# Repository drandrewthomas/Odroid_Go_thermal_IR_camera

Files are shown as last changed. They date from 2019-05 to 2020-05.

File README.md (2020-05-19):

# Odroid Go thermal infrared camera

## Update 28th April 2020: The firmware has been updated to v1.1, with lots of new features and improvements!

## Introduction

This is a simple, yet very useful, IR (infrared) thermal camera project for the Odroid Go handheld ESP32 system. It allows saving of data to an SD card as well as having a Bluetooth interface to wirelessly get data off the camera to a computer, tablet or mobile phone. It's based on the MLX90640 32x24 pixel infrared thermal array modules that you can get relatively inexpensively many places online. Here's a short list of some of it's features:

* Onscreen display of the IR image, with a movable cursor to let you query the temperature for any single pixel (press up, down, left and right on the + control to move the cursor).
* A range of colour maps, which are easily added to in the Arduino code.
* A zoom button so you can switch the IR image to/from full-screen mode.
* Saving of data to the SD card on your ODroid GO in text CSV format for later analysis.
* A fever screening colour map, which shows temperatures above 36C in red to indicate when checking for a fever may be necessary (not for medical diagnosis).
* In fever checking mode IR images with temperatures above 36C are indicated by an audible beep, to help with rapid screening of your family and friends.
* An on-screen battery indicator, so you know when to recharge your GO.
* A Bluetooth interface that lets you take full control of the IR camera, including transferring the IR data to a PC as ASCII text or binary data.
* 3D printing STL files to make a forward-facing or rear-facing case to protect your thermal IR module.

Below is a photo of the project in action on an Odroid GO:

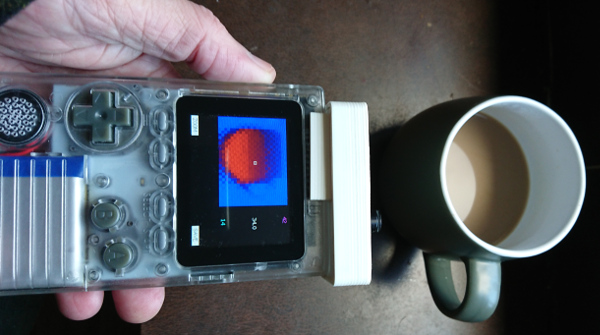
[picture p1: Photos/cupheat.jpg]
The thermal camera in action


## Using the Arduino code

There are two ways to use the thermal camera code. The really simple way is to go to the 'FW file' folder and copy the 'goircam.fw' file to the firmware folder on your Odroid Go SD card. Then when you turn the Go on with the B button held down you should get an option to load the camera firmware. Obviously you'll need the camera built and attached for the firmware to run.

The more advanced way is for people who want to use the Arduino IDE to edit or build the firmware. To do that just use the files in the 'Arduino code' folder as you would do for code in any other Arduino project you have. All of the details are available on the Odroid Go website for setting up the Arduino IDE for the Go, so I won't cover it here.

If you're using the Arduino IDE method and want to create a firmware file, as described on the Go site, the graphics for use with the MKFW utility are included in the 'Graphics' folder.

## Building the thermal camera module

Building the module is very simple, as it uses just the MLX90640 module, with wires for ground, VCC, SCL and SDA (so just power and I2C). According to the Go wiki the header pinout is as follows, so you can wire the module easily even just using some wires and a breadboard.

| Header Pin | Function |
| --- |:---:|
| 1 | GND |
| 4 | SDA |
| 5 | SCL |
| 6 | VCC |

Once you've got things wired up and tested, the simplicity of the circuit makes it very simple to solder up some header pins on a piece of veroboard to make a more robust connector for the Odroid Go header sockets. Below is a photo of how I did that. I put the header pins on top of the veroboard and soldered the wires to the track on the back, which meant the wires didn't obstruct the connection, although you could just use a bigger piece of veroboard too.

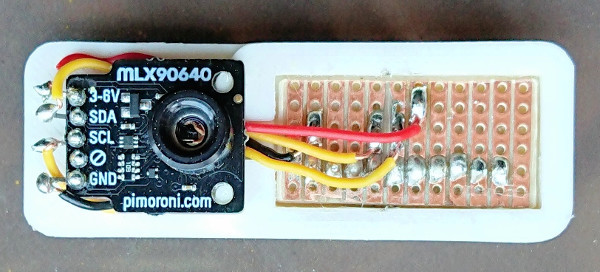
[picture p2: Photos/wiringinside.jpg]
A photo of the circuit


## Making a 3D printed enclosure

The 'Case 3D model' folder includes files I used to make 3D printed enclosures. The STL files are designed for the Pimoroni MLX90640 module I used. If that doesn't work for your needs, or the MLX90640 module you have, the OpenSCAD files are included so you can make a custom version. By cutting the veroboard to the right size the IR module should fit perfectly into the back of the enclosure, leaving the header pins properly positioned as shown in the front-facing example photo below. The veroboard was glued in, and it's necessary to check the pins as the glue goes off to make sure they stay perpendicular to the enclosure.

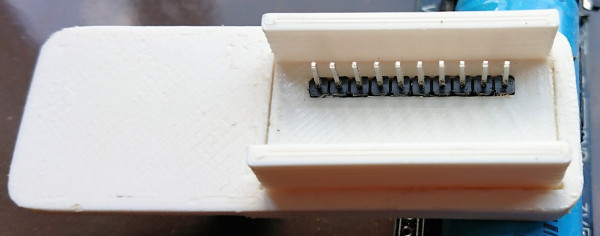
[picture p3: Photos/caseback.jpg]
A photo of the back of the enclosure showing the header pins glued in


## Useful links

Below are some links that may be useful if you decide to build this project.

The Odroid Go Wiki is a useful resource for all Go things: [https://wiki.odroid.com/odroid_go/odroid_go](https://wiki.odroid.com/odroid_go/odroid_go)

The Wiki page for a 16x2 I2C LCD project contains details of how to connect an I2C module to the Go header: [https://wiki.odroid.com/odroid_go/arduino/09_16x2lcd_i2c](https://wiki.odroid.com/odroid_go/arduino/09_16x2lcd_i2c)

The front facing 3D printed case can also be downloaded from Thingiverse: [https://www.thingiverse.com/thing:3648653](https://www.thingiverse.com/thing:3648653)

And the rear facing 3D printed case can also be downloaded from MyMiniFactory: [https://www.myminifactory.com/object/3d-print-odroid-go-thermal-infrared-ir-camera-ideal-for-covid-coronavirus-screening-122446](https://www.myminifactory.com/object/3d-print-odroid-go-thermal-infrared-ir-camera-ideal-for-covid-coronavirus-screening-122446)

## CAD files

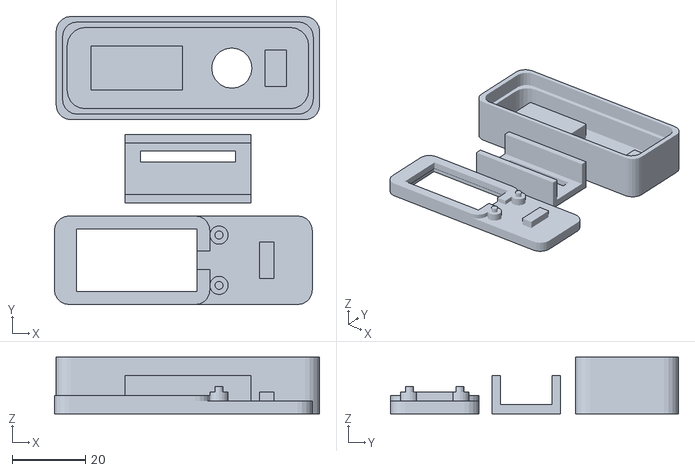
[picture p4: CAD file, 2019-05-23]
Case 3D model/Front facing version/goircam_v1.stl
72.5 x 78.7 x 15.5

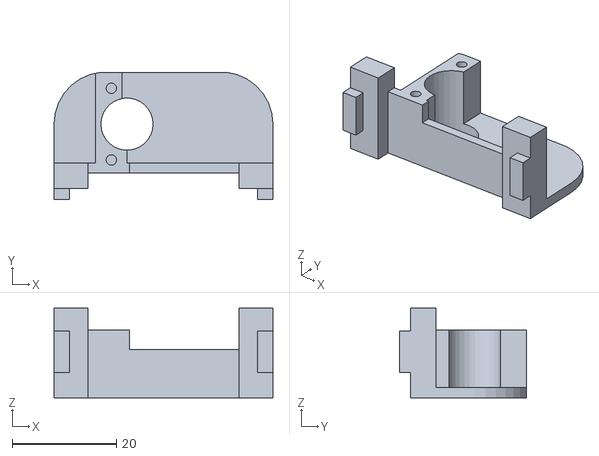
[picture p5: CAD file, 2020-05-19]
Case 3D model/Rear facing version/holddown.stl
42.0 x 24.4 x 17.2

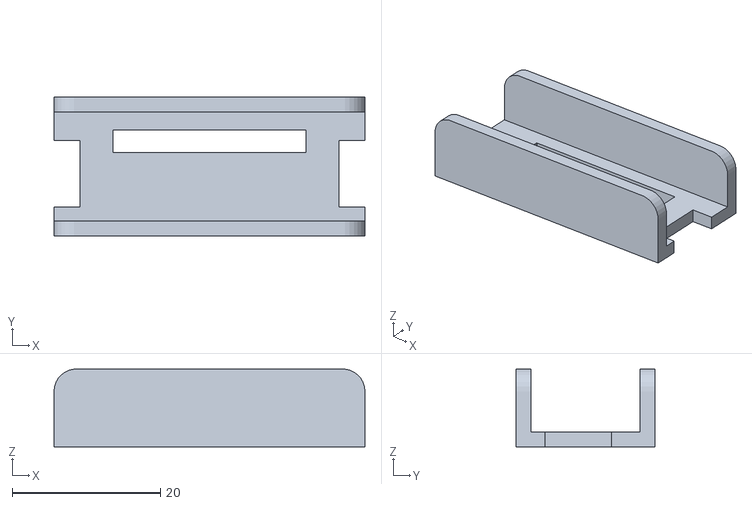
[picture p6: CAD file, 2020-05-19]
Case 3D model/Rear facing version/headeradapter.stl
42.0 x 18.8 x 10.5

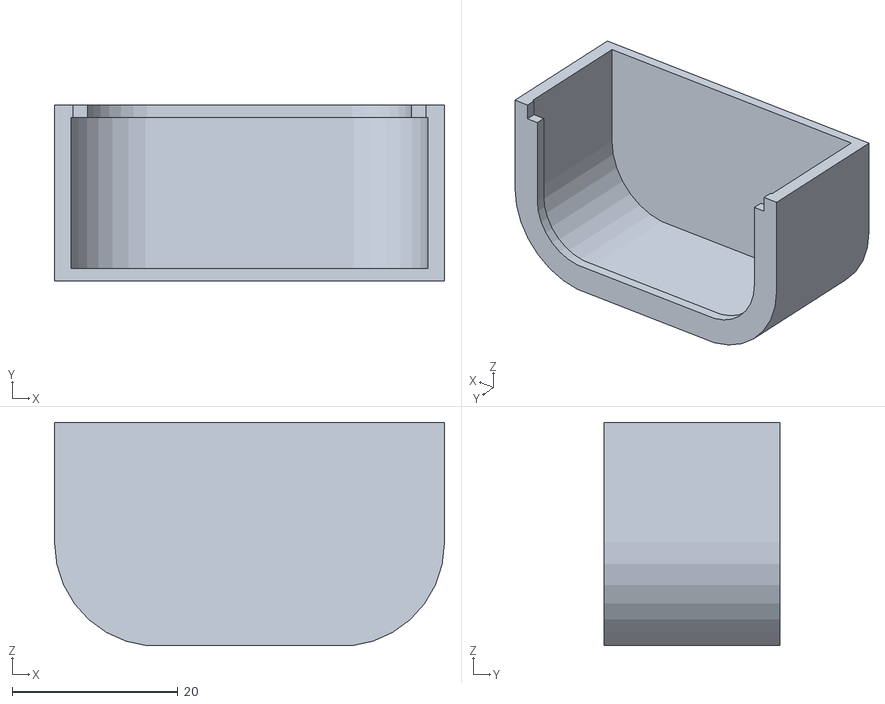
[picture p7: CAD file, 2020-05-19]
Case 3D model/Rear facing version/cover.stl
47.0 x 21.2 x 26.9

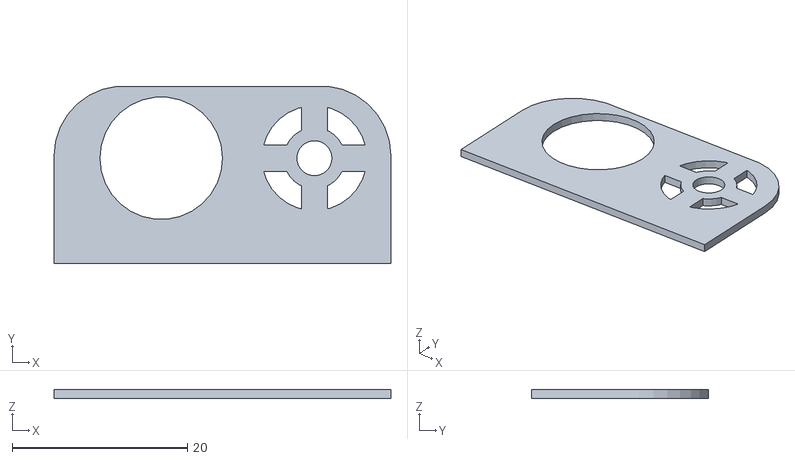
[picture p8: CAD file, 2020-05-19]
Case 3D model/Rear facing version/fascia.stl
38.5 x 20.3 x 1.00

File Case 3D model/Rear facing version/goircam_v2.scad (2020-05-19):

$fn=30;
trad=10;
brad=3;

//rotate([0,180,0]) makeheaderadapter();
//rotate([-90,0,0]) makeholddown();
//rotate([-90,0,0]) makefascia();
rotate([0,180,0]) makecover();

module makecover()
{
  color("#0000ff")
  {
    difference()
    {
      translate([0,0,0]) roundedbox(42+5,33+5,18.75+2.5,10+2.5,3);
      translate([0,0,0]) roundedbox(42+1,33+1,18.75+2.5-3,10,3);
      translate([0,10,0]) roundedbox(42-5+2,33-5+2,5,8,3);
      translate([0,0,-33+10.5-2]) cube([100,100,33],center=true);
      intersection()
      {
        translate([0,10,2.25]) roundedbox(42.5,33,18.75,10,3);
        translate([0,10,-16+2.25]) cube([100,100,16],center=true);
      }
    }
  }
}

module makeheaderadapter()
{
  difference()
  {
    roundedbox(42,33,18.75,10,3);
    translate([0,0,-16]) cube([45,14.7,16],center=true);
    translate([0,3.4,-16.5+8]) cube([26,3,6],center=true);
    translate([0,0,33-25+2.5]) cube([45,45,25+8],center=true);
    translate([21-1.5,-1,-6]) cube([3+1,8+1,40],center=true);
    translate([-21+1.5,-1,-6]) cube([3+1,8+1,40],center=true);
  }
}

module makeholddown()
{
  color("#ff0000")
  {
    union()
    {
      difference()
      {
        roundedbox(42,33,18.75,10,3);
        translate([0,0,-33+10.5+0.2]) cube([100,100,33],center=true);
        translate([0,18.75/2,0]) cube([100,3,100],center=true);
        translate([21,-3.5,12.5+3]) cube([56,18.75,33],center=true);
        translate([21-1,-3.5,12.5+3+10]) cube([56,18.75,33],center=true);
        translate([-21,-3.5,12.5+3]) cube([16,18.75,33],center=true);
        translate([0,-5-9.5,12.5+3]) cube([50,18.75,33],center=true);
        translate([0,0,-4.35]) cube([29,50,3],center=true);
        translate([4,-18.75/2,-2]) cube([21,16,3],center=true);
        translate([-4,-18.75/2,-2]) cube([21,8.5,3],center=true);
        translate([-7,8,6.5]) rotate([90,0,0]) cylinder(h=50,r=5,center=true);
        translate([-10,-5,6.5+(13.75/2)]) rotate([90,0,0]) cylinder(h=15,r=1,center=true);
        translate([-10,-5,6.5-(13.75/2)]) rotate([90,0,0]) cylinder(h=15,r=1,center=true);
      }
      translate([21-1.5,-1,-6]) cube([3,8,4],center=true);
      translate([-21+1.5,-1,-6]) cube([3,8,4],center=true);
    }
  }
}

module makefascia()
{
  color("#00ff00")
  {
    difference()
    {
      roundedbox(42-5+2-0.5,33-5+2-0.5,1,8,3);
      translate([0,0,-33+10.5+0.2+0.25]) cube([100,100,33],center=true);
      translate([-7,8,6.5]) rotate([90,0,0]) cylinder(h=50,r=7,center=true);
      difference()
      {
        translate([10.5,8,6.5]) rotate([90,0,0]) cylinder(h=50,r=6,center=true);
        translate([10.5,8,6.5]) cube([3,100,100],center=true);
        translate([10.5,8,6.5]) cube([100,100,3],center=true);
        translate([10.5,8,6.5]) rotate([90,0,0]) cylinder(h=50,r=3.5,center=true);
      }
      translate([10.5,8,6.5]) rotate([90,0,0]) cylinder(h=50,r=2,center=true);
    }
  }
}

module roundedbox(w,h,d,trad,brad)
{
  hull()
  {
    translate([-(w/2)+brad,0,-(h/2)+brad]) rotate([90,0,0]) cylinder(h=d,r=brad,center=true);
    translate([(w/2)-brad,0,-(h/2)+brad]) rotate([90,0,0]) cylinder(h=d,r=brad, center=true);
    translate([(w/2)-trad,0,(h/2)-trad]) rotate([90,0,0]) cylinder(h=d,r=trad,center=true);
    translate([-(w/2)+trad,0,(h/2)-trad]) rotate([90,0,0]) cylinder(h=d,r=trad,center=true);
  }
}

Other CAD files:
Case 3D model/Front facing version/goircam_v1.scad

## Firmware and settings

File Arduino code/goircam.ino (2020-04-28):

#include <odroid_go.h>
#include <driver/adc.h>
#include "sensors/Wire.h"
#include "MLX90640_I2C_Driver.h"
#include "MLX90640_API.h"
#include "BluetoothSerial.h"
#include "FS.h"
#include "SD.h"
#include "SPI.h"

#define RESISTANCE_NUM 2
#define DEFAULT_VREF 1100
static esp_adc_cal_characteristics_t adc_chars;

#define TA_SHIFT 8 //Default shift for MLX90640 in open air
const byte MLX90640_address = 0x33;
static float mlx90640To[768];
paramsMLX90640 mlx90640;

BluetoothSerial serialBT;

bool dooverlay=true,saved=false,havesd=false;
int boxx=16,boxy=12,cmap=0,cr,cg,cb;
long gottime,firstsave=-1,battime;
float ambient,battery,fever=36,mn,mx;

void setup()
{
  Serial.begin(115200); // MUST BE BEFORE GO.BEGIN()!!!!!
  serialBT.begin("GO IR Camera");
  GO.begin();
  Wire.begin(15,4);
  Wire.setClock(400000);
  Serial.println("Starting...");
  Serial.println();
  adc1_config_width(ADC_WIDTH_BIT_12);
  adc1_config_channel_atten(ADC1_CHANNEL_0, ADC_ATTEN_DB_11);
  esp_adc_cal_characterize(ADC_UNIT_1, ADC_ATTEN_DB_11, ADC_WIDTH_BIT_12, DEFAULT_VREF, &adc_chars);
  int status;
  uint16_t eeMLX90640[832];
  status = MLX90640_DumpEE(MLX90640_address, eeMLX90640);
  if (status != 0)
    Serial.println("Failed to load system parameters");
  status = MLX90640_ExtractParameters(eeMLX90640, &mlx90640);
  if (status != 0)
    Serial.println("Parameter extraction failed");
  MLX90640_SetRefreshRate(MLX90640_address,0x03);
  if(SD.begin()) havesd=true;
  else Serial.println("Card Mount Failed");
  GO.lcd.setTextFont(4);
  GO.lcd.setTextColor(WHITE);
  GO.lcd.setTextDatum(MC_DATUM);
//  GO.lcd.setCursor(160,120);
  GO.lcd.drawString("IR Camera v1.1",160,80);
  GO.lcd.setTextFont(2);
  GO.lcd.drawString("by Andrew Thomas",160,150);
  GO.lcd.drawString("2019-2020",160,170);
  GO.lcd.setTextFont(4);
  delay(1000);
  Serial.println("Getting initial IR frame...");
  getirframe();
  calcminmax();
  drawtodisplay(true);
  Serial.println("Setup done");
}

void loop()
{
  char inbyte;
  if(serialBT.available()>0)
  {
    inbyte=serialBT.read();
    switch(inbyte)
    {
      case '0': cmap=0; break;
      case '1': cmap=1; break;
      case '2': cmap=2; break;
      case 'a': sendtoserialtext();
                break;
      case 'b': sendtoserialbinary();
                break;
      case 'd': getirframe();
                calcminmax();
                break;
      case 'n': makebeep(2000,500);
                break;
      case 'o': dooverlay=true;
                break;
      case 's': savetosdcard();
                saved=true;
                break;
      case 'u': drawtodisplay(true);
                break;
      case 'v': serialBT.println("IR Camera v1.1");
                break;
      case 'z': dooverlay=false;
                break;
    }
  }
  GO.update();
  if(GO.BtnA.isPressed()==1)
  {
    getirframe();
    calcminmax();
    drawtodisplay(true);
    if(mx>=fever && cmap==2) makebeep(3000,1000);
  }
  if(GO.BtnMenu.isPressed()==1)
  {
    while(GO.BtnMenu.isPressed()==1){GO.update();delay(50);}
    if(dooverlay==true) dooverlay=false;
    else dooverlay=true;
    GO.lcd.clearDisplay();
    drawtodisplay(true);
  }
  if(GO.BtnVolume.isPressed()==1)
  {
    while(GO.BtnVolume.isPressed()==1){GO.update();delay(50);}
    cmap++;
    if(cmap>2) cmap=0;
    drawtodisplay(false);
  }
  if(GO.BtnSelect.isPressed()==1)
  {
    while(GO.BtnSelect.isPressed()==1){GO.update();delay(50);}
  }
  if(GO.BtnStart.isPressed()==1)
  {
    if(saved==false)
    {
      savetosdcard();
      saved=true;
      drawtodisplay(true);
    }
  }
  if(GO.JOY_Y.isAxisPressed()==1)
  {
    if(boxy<23 && dooverlay==true)
    {
      boxy++;
      drawtodisplay(false);
      delay(50);
    }
  }
  if(GO.JOY_Y.isAxisPressed()==2)
  {
    if(boxy>0 && dooverlay==true)
    {
      while(GO.JOY_Y.isAxisPressed()!=0){GO.update();delay(50);}
      boxy--;
      drawtodisplay(false);
      delay(50);
    }
  }
  if(GO.JOY_X.isAxisPressed()==1)
  {
    if(boxx<31 && dooverlay==true)
    {
      while(GO.JOY_X.isAxisPressed()!=0){GO.update();delay(50);}
      boxx++;
      drawtodisplay(false);
      delay(50);
    }
  }
  if(GO.JOY_X.isAxisPressed()==2)
  {
    if(boxx>0 && dooverlay==true)
    {
      while(GO.JOY_X.isAxisPressed()!=0){GO.update();delay(50);}
      boxx--;
      drawtodisplay(false);
      delay(50);
    }
  }
  if((millis()-battime)>30000) updatebattery();
}

void updatebattery()
{
  readbattery();
  drawbattery();
}

void calcminmax()
{
  int c;
  mn=99999,mx=-99999;
  for(c=0;c<768;c++)
  {
    if(mlx90640To[c]>mx) mx=mlx90640To[c];
    if(mlx90640To[c]<mn) mn=mlx90640To[c];
  }
  mn=int(mn);
  mx=int(mx+1);
  if(mn<-30) mn=-30;
  if(mx>300) mx=300;  
}

void drawtodisplay(bool cls)
{
  float mid,val;
  uint16_t x,y,ind,r,g,b,col;
  uint16_t xw=10,yw=10,xoff=0,yoff=0;
  if(dooverlay==true)
  {
    xw=7;
    yw=7;
    xoff=0;
    yoff=0;
  }
  mid=mlx90640To[((23-boxy)*32)+boxx];
  if(cls==true) GO.lcd.clearDisplay();
  for(y=0;y<24;y++)
  {
    for(x=0;x<32;x++)
    {
      ind=(y*32)+x;
      val=mlx90640To[ind];
      docolourmapping(val,mn,mx);
      col=GO.lcd.color565(cr,cg,cb);
      GO.lcd.fillRect(xoff+(x*xw),yoff+((24*yw)-(y*yw)),xw,yw,col);
    }
  }
  if(dooverlay==true)
  {
    if(cls==false) GO.lcd.fillRect(xoff+(32*xw)+5,0,320-(xoff+(32*xw)),210,BLACK);
    GO.lcd.setTextFont(2);
    GO.lcd.setTextSize(1);
    GO.lcd.setTextDatum(ML_DATUM);
    GO.lcd.setTextColor(MAGENTA,BLACK);
    GO.lcd.drawNumber(int(mx),255,yoff+15);
    GO.lcd.setTextColor(CYAN,BLACK);
    GO.lcd.drawNumber(int(mn),255,yoff+(24*yw)-2);
    GO.lcd.setTextColor(WHITE,BLACK);
    GO.lcd.drawFloat(mid,1,255,yoff+((24*yw)/2)+yw);
    GO.lcd.drawRect(xoff+(boxx*xw),yoff+(boxy*yw),xw,yw,WHITE);
    // Draw button labels
    GO.lcd.setTextFont(2);
    GO.lcd.setTextSize(1);
    GO.lcd.setTextColor(BLACK,WHITE);
    GO.lcd.setTextDatum(ML_DATUM);
    GO.lcd.drawString(" ZOOM ",0,230);
    switch(cmap)
    {
      case 0: GO.lcd.drawString(" B R ",82,230);
      break;
      case 1: GO.lcd.drawString(" Y R ",82,230);
      break;
      case 2: GO.lcd.drawString(" FEV ",82,230);
      break;
    }
    if(saved==false && havesd==true)
    {
      GO.lcd.setTextDatum(MR_DATUM);
      GO.lcd.drawString(" SAVE  ",320,230);
    }
    GO.lcd.setTextFont(2);
    GO.lcd.setTextSize(1);
    GO.lcd.setTextColor(WHITE,BLACK);
    GO.lcd.drawString("Ambient: "+String(ambient,1)+" C",2,195);
  }
  drawbattery();
}

void drawbattery()
{
  int c,bat,nb,xoff=320-44,yoff=194;
  uint16_t col;
  if(dooverlay==false) yoff+=30;
  col=GO.lcd.color565(0,0,0);
  GO.lcd.fillRect(xoff-4,yoff-4,44,18,col);
  bat=int(map(constrain(battery,3.2,4),3.2,4,0,100));
  nb=bat/20;
  if(nb<=1)
  {
    nb=1;
    col=GO.lcd.color565(255,0,0);
  }
  else col=GO.lcd.color565(0,255,0);
  for(c=0;c<nb;c++)
    GO.lcd.fillRect(xoff+(c*7),yoff,5,10,col);
  col=GO.lcd.color565(255,255,255);
  GO.lcd.drawLine(xoff-3,yoff-3,xoff+36,yoff-3,col);
  GO.lcd.drawLine(xoff-3,yoff+12,xoff+36,yoff+12,col);
  GO.lcd.drawLine(xoff-3,yoff-3,xoff-3,yoff+12,col);
  GO.lcd.drawLine(xoff+36,yoff-3,xoff+36,yoff+2,col);
  GO.lcd.drawLine(xoff+36,yoff+7,xoff+36,yoff+12,col);
  GO.lcd.drawLine(xoff+39,yoff+2,xoff+39,yoff+7,col);
  GO.lcd.drawLine(xoff+36,yoff+2,xoff+39,yoff+2,col);
  GO.lcd.drawLine(xoff+36,yoff+7,xoff+39,yoff+7,col);
}

void docolourmapping(float t,float mn,float mx)
{
  switch(cmap)
  {
    case 0: // Red/blue mapping
            cr=int(map(t,int(mn),int(mx),0,255));
            cg=0;
            cb=int(map(t,int(mn),int(mx),255,0));
            break;
    case 1: // Yellow mapping
            cr=255;
            cg=int(map(t,int(mn),int(mx),255,0));
            cb=0;
            break;
    case 2: // Fever mapping
            if(t<=fever)
            {
              cr=0;
              cg=0;
              cb=int(map(t,int(mn),fever,255,50));
            }
            else
            {
              cr=int(map(t,fever,int(mx),50,255));
              cg=0;
              cb=0;
            }
            break;
  }
}

void getirframe()
{
  for (byte x = 0 ; x < 2 ; x++) //Read both subpages
  {
    uint16_t mlx90640Frame[834];
    int status = MLX90640_GetFrameData(MLX90640_address, mlx90640Frame);
    if (status < 0)
    {
      Serial.print("GetFrame Error: ");
      Serial.println(status);
    }
    float vdd = MLX90640_GetVdd(mlx90640Frame, &mlx90640);
    float Ta = MLX90640_GetTa(mlx90640Frame, &mlx90640);
    float tr = Ta - TA_SHIFT; //Reflected temperature based on the sensor ambient temperature
    float emissivity = 0.95;
    MLX90640_CalculateTo(mlx90640Frame, &mlx90640, emissivity, tr, mlx90640To);
    ambient=Ta;
  }
  gottime=millis();
  boxx=16,boxy=12;
  saved=false;
  readbattery();
}

void sendtoserialtext()
{
  int x,y,ind;
  float val;
  if(firstsave==-1)
  {
    firstsave=millis();
    serialBT.print("0");
  }
  else serialBT.print(gottime-firstsave,DEC);
  serialBT.print(',');
  for(y=0;y<24;y++)
  {
    for(x=0;x<32;x++)
    {
      ind=(y*32)+x;
      val=mlx90640To[ind];
      serialBT.print(val,2);
      serialBT.print(',');
    }
  }
  serialBT.print(ambient,2);
  serialBT.print(',');
  serialBT.println(battery,2);
}

void sendtoserialbinary()
{
  int x,y,ind,val;
  serialBT.write(254);
  serialBT.write(254);
  for(y=0;y<24;y++)
  {
    for(x=0;x<32;x++)
    {
      ind=(y*32)+x;
      val=int((mlx90640To[ind]+50)*100);
      serialBT.write(highByte(val));
      serialBT.write(lowByte(val));
    }
  }
  val=int((ambient+50)*100);
  serialBT.write(highByte(val));
  serialBT.write(lowByte(val));
  val=int(battery*100);
  serialBT.write(highByte(val));
  serialBT.write(lowByte(val));
  serialBT.write(255);
  serialBT.write(255);
}

boolean isConnected()
{
  Wire.beginTransmission((uint8_t)MLX90640_address);
  if (Wire.endTransmission() != 0)
    return (false); //Sensor did not ACK
  return (true);
}

void savetosdcard()
{
  int x,y,ind;
  float val;
  File file=SD.open("/goircam.csv",FILE_APPEND);
  if(!file)
  {
    Serial.println("Failed to open file for appending");
    makebeep(500,500);
    return;
  }
  file.print(gottime,DEC);
  file.print(',');
  for(y=0;y<24;y++)
  {
    for(x=0;x<32;x++)
    {
      ind=(y*32)+x;
      val=mlx90640To[ind];
      file.print(val,2);
      file.print(',');
    }
  }
  file.println(ambient,DEC);
  file.close();
}

void makebeep(int pitch,int duration)
{
  GO.Speaker.setVolume(100);
  GO.Speaker.begin();
  GO.Speaker.tone(pitch,duration);
  delay(duration);
  GO.Speaker.end();
  delay(100);
}

void readbattery()
{
  int c;
  battery=0;
  for(c=0;c<10;c++)
    battery+=float(esp_adc_cal_raw_to_voltage(adc1_get_raw(ADC1_CHANNEL_0), &adc_chars)) * RESISTANCE_NUM / 1000;
  battery/=10;
  battime=millis();
}

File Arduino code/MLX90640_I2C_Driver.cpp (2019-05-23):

/**
   @copyright (C) 2017 Melexis N.V.

   Licensed under the Apache License, Version 2.0 (the "License");
   you may not use this file except in compliance with the License.
   You may obtain a copy of the License at

       http://www.apache.org/licenses/LICENSE-2.0

   Unless required by applicable law or agreed to in writing, software
   distributed under the License is distributed on an "AS IS" BASIS,
   WITHOUT WARRANTIES OR CONDITIONS OF ANY KIND, either express or implied.
   See the License for the specific language governing permissions and
   limitations under the License.

*/

#include <odroid_go.h>
#include "sensors/Wire.h"
//#include <Wire.h>

#include "MLX90640_I2C_Driver.h"

void MLX90640_I2CInit()
{

}

//Read a number of words from startAddress. Store into Data array.
//Returns 0 if successful, -1 if error
int MLX90640_I2CRead(uint8_t _deviceAddress, unsigned int startAddress, unsigned int nWordsRead, uint16_t *data)
{

  //Caller passes number of 'unsigned ints to read', increase this to 'bytes to read'
  uint16_t bytesRemaining = nWordsRead * 2;

  //It doesn't look like sequential read works. Do we need to re-issue the address command each time?

  uint16_t dataSpot = 0; //Start at beginning of array

  //Setup a series of chunked I2C_BUFFER_LENGTH byte reads
  while (bytesRemaining > 0)
  {
    Wire.beginTransmission(_deviceAddress);
    Wire.write(startAddress >> 8); //MSB
    Wire.write(startAddress & 0xFF); //LSB
    if (Wire.endTransmission(false) != 0) //Do not release bus
    {
//      Serial.println("No ack read");
//      return (0); //Sensor did not ACK
    }

    uint16_t numberOfBytesToRead = bytesRemaining;
    if (numberOfBytesToRead > I2C_BUFFER_LENGTH) numberOfBytesToRead = I2C_BUFFER_LENGTH;

    Wire.requestFrom((uint8_t)_deviceAddress, numberOfBytesToRead);
    if (Wire.available())
    {
      for (uint16_t x = 0 ; x < numberOfBytesToRead / 2; x++)
      {
        //Store data into array
        data[dataSpot] = Wire.read() << 8; //MSB
        data[dataSpot] |= Wire.read(); //LSB

        dataSpot++;
      }
    }

    bytesRemaining -= numberOfBytesToRead;

    startAddress += numberOfBytesToRead / 2;
  }

  return (0); //Success
}

//Set I2C Freq, in kHz
//MLX90640_I2CFreqSet(1000) sets frequency to 1MHz
void MLX90640_I2CFreqSet(int freq)
{
  //i2c.frequency(1000 * freq);
  Wire.setClock((long)1000 * freq);
}

//Write two bytes to a two byte address
int MLX90640_I2CWrite(uint8_t _deviceAddress, unsigned int writeAddress, uint16_t data)
{
  Wire.beginTransmission((uint8_t)_deviceAddress);
  Wire.write(writeAddress >> 8); //MSB
  Wire.write(writeAddress & 0xFF); //LSB
  Wire.write(data >> 8); //MSB
  Wire.write(data & 0xFF); //LSB
  if (Wire.endTransmission() != 0)
  {
    //Sensor did not ACK
//    Serial.println("Error: Sensor did not ack");
//    return (-1);
  }

  uint16_t dataCheck;
  MLX90640_I2CRead(_deviceAddress, writeAddress, 1, &dataCheck);
  if (dataCheck != data)
  {
    //Serial.println("The write request didn't stick");
    return -2;
  }

  return (0); //Success
}

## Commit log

2020-05-19 Moved to new folder.
    [goircam_v1.scad, goircam_v1.stl]
2020-05-19 Initial commit.
    [cover.stl, fascia.stl, goircam_v2.scad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]
2020-05-19 Added rear facing camera case.
